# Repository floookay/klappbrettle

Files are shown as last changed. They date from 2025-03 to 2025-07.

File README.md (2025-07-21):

> [!CAUTION]
> This is still a work in progress and not yet fully tested! I messed up my last order from Mouser and need to get the missing components the next time I get to order.

# klappbrettle

a 40% ortho keyboard with a hinge

## design

I love using ortho keyboards but non-split ortho keyboards are getting uncomfortable for me fast so I thought about adding a hinge at the top.

It kind of resembles a starter clapper so that's where it got its name and athletics theme.

## pcb

PCBWay ([PCBWay.com](https://pcbway.com)) kindly offered to sponsor the pcb for this project that's why I got my hands on the pcbs within almost a week after ordering.  
The order process is straight forward and you also get an instant quote before ordering. After placing the order a technician checked and corrected the drill holes of the mouse bits within a few hours and the pcb was sent to manufacturing.
I'm impressed with the speed an quality of the pcb, see below:

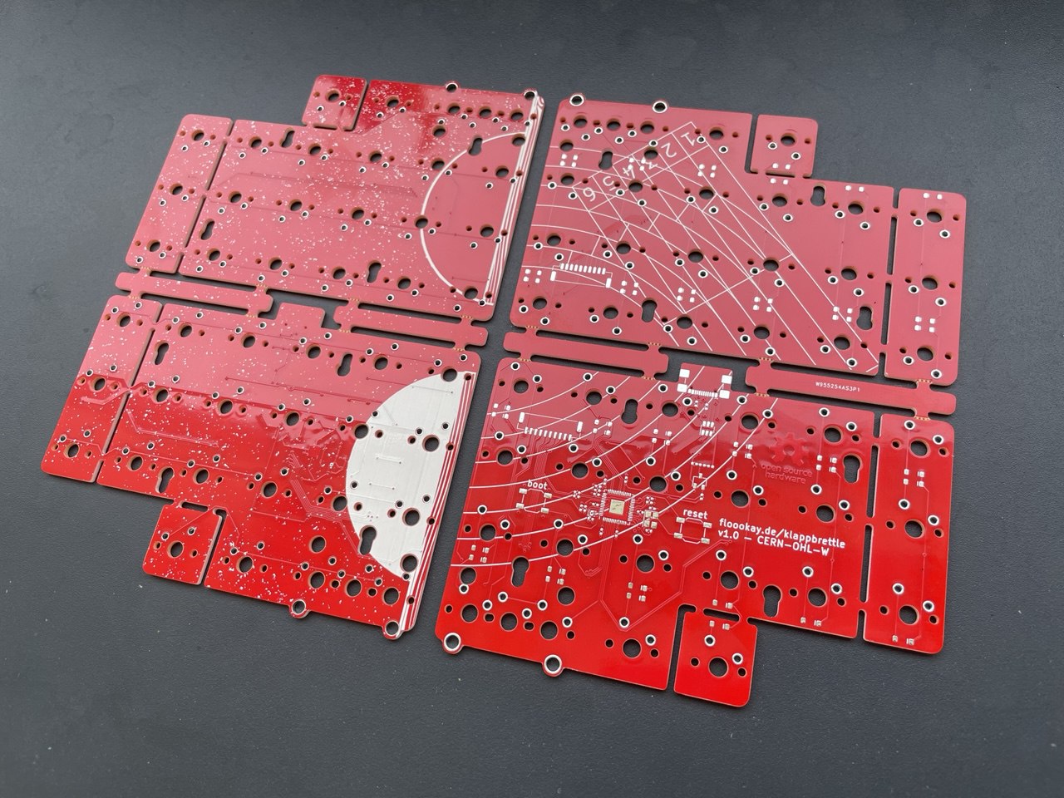
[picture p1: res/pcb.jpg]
pcb


The pcb is a two panel design where both sides are connected via a 10 pin JST connector. It's powered by a RP2040 microcontroller so there is plenty of flash storage. You can clip off the mod columns or the outer thumb key if want to. There are also extra holes where you can put grommets so the switches don't pop out of the 3mm plate.

- [x] complete the pcb design
- [ ] order missing components and solder

## case

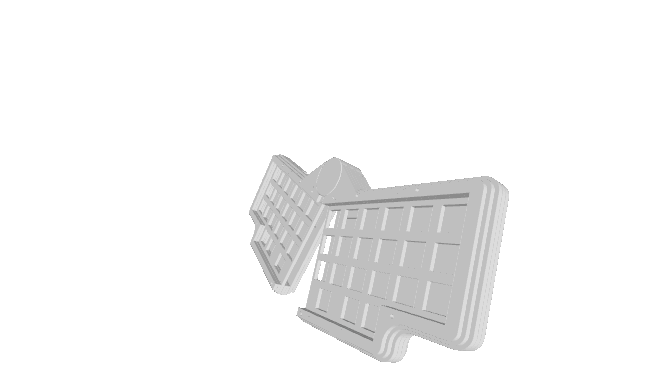
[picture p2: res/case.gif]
case gif, generated via imagetostl.com


The case is a 3mm acryl sandwich style case with a hinge to connect the halves and route the cable through. The hinge can be either 3d printed or can be 3mm acryl as well. I still need to test what works best, so far I only have a 3d printed prototype at hand.

- [x] complete the acrylic case design
- [ ] make the bottom plates look a bit nicer
- [ ] prepare dxf files and variants for laser cutting

## firmware

This will be powered by QMK but the firmware isn't ready yet.

- [ ] finish qmk firmware
- [ ] add vial support

## acknowledgements

Huge thanks to PCBWay for offering to sponsor this project, hlord2000 for their [RP2040 KiCAD template](https://github.com/hlord2000/Ohmbedded-RP2040-PCB-Template) as well as the ClackTales community for helping me with the theme.

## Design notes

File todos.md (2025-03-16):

- case usb cutout
- test print
- pcb mouse cuts
- pcb routing

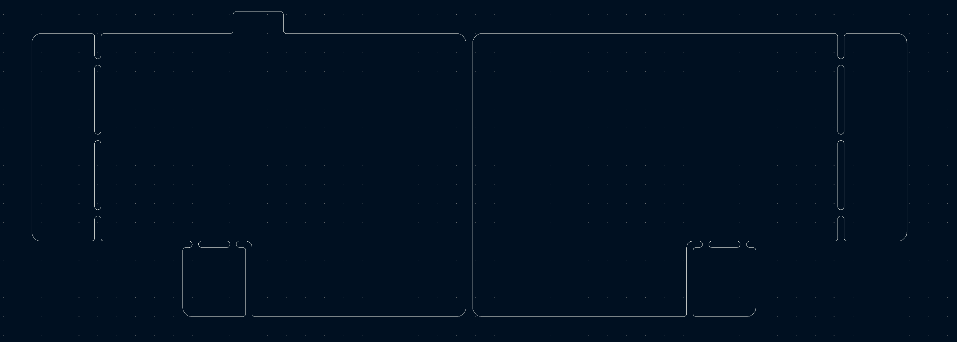
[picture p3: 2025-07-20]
pcb/outline.png

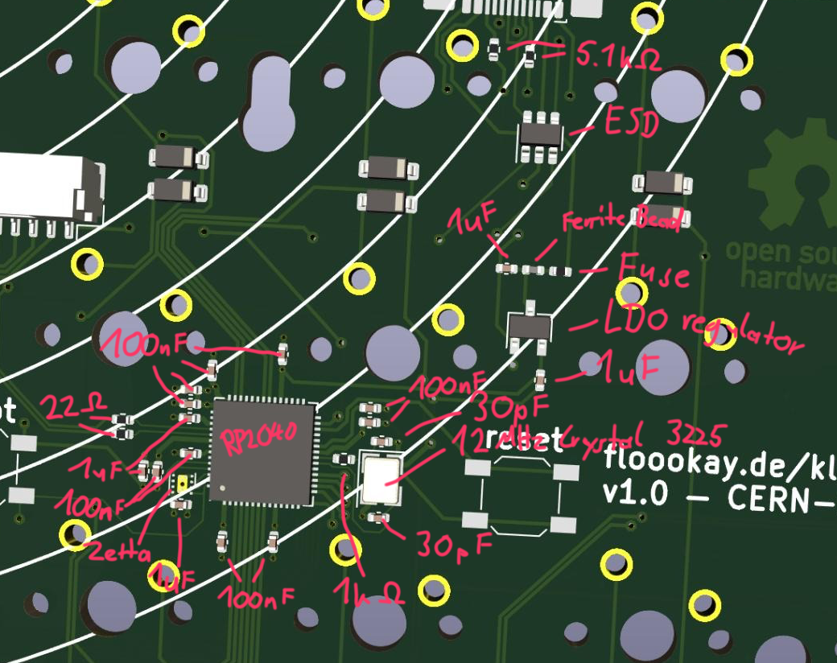
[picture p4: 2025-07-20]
pcb/placement.png

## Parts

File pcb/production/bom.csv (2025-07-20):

Designator | Footprint | Quantity | Value | LCSC Part #
C1, C2 | 0402 | 2 | 30p | C1562
C10, C12, C13, C15, C3 | 0402 | 5 | 1u | C52923
C11, C14, C16, C17, C4, C5, C6, C7, C8, C9 | 0402 | 10 | 100n | C1525
D1, D10, D11, D12, D13, D14, D15, D16, D17, D18, D19, D2, D20, D21, D22, D23, D24, D25, D26, D27, D28, D29, D3, D30, D31, D32, D33, D34, D35, D36, D37, D38, D39, D4, D40, D41, D42, D43, D44, D5, D6, D7, D8, D9 | D_SOD-123-minimal | 44 | D_45deg
F1 | 0402 | 1 | 700mA | C914086
FB1 | 0402 | 1 | 100 Ohm @ 100 MHz | C85812
J1 | USB_C_Receptacle_GCT_USB4110 | 1 | USB_C_Receptacle_USB2.0 | C9002
J2, J3 | JST_GH_SM10B-GHS-TB_1x10-1MP_P1.25mm_Horizontal | 2 | Conn_01x10 | C2683602
MX1, MX10, MX11, MX12, MX13, MX14, MX15, MX16, MX17, MX18, MX19, MX2, MX20, MX21, MX22, MX23, MX24, MX25, MX26, MX27, MX28, MX29, MX3, MX30, MX31, MX32, MX33, MX34, MX35, MX36, MX37, MX38, MX39, MX4, MX40, MX41, MX42, MX43, MX44, MX45, MX46, MX5, MX6, MX7, MX8, MX9 | SW_MX_1u | 46 | MX_SW_solder
R1, R2 | 0402 | 2 | 22 | C25152
R3 | 0402 | 1 | 1k | C106235
R4, R5 | 0402 | 2 | 5.1k | C25905
S1, S2 | STAB_MX_P_2u | 2 | MX_stab
SW72, SW73 | SW_SPST_SKQG_WithoutStem | 2 | SW_Push | C115351
U1 | QFN-56-1EP_7x7mm_P0.4mm_EP3.2x3.2mm_ThermalVias | 1 | RP2040 | C2040
U3 | SOT-23-6 | 1 | USBLC6-2SC6 | C558442
U4 | TSOT-23 | 1 | 3.3V Fixed Regulator | C150715
U5 | USON-8_1.5x1.5mm_P0.45mm | 1 | ZD25D40CNJGR | C3646778
Y1 | Crystal_SMD_3225-4Pin_3.2x2.5mm | 1 | 12MHz Crystal 3225 | C9002

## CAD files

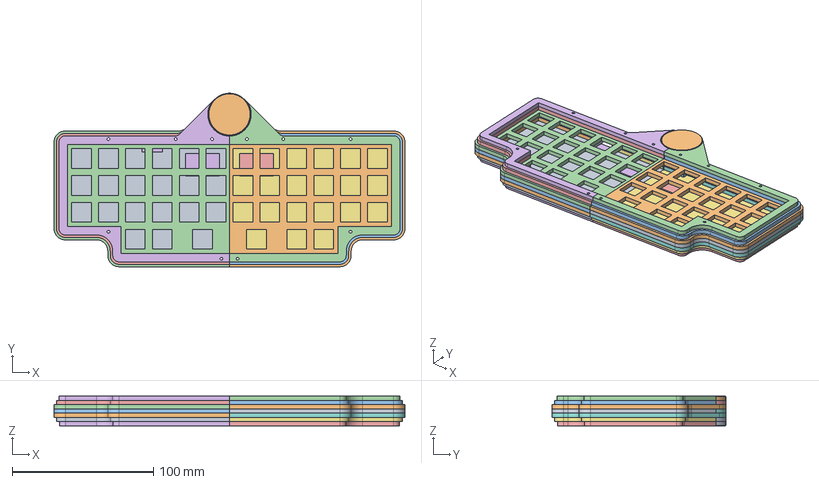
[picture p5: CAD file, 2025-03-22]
acrylic case/case.FCStd
248.6 x 122.9 x 21.0 mm
left_0_bottom
left_1_spacer
left_2_spacer
left_3_plate
left_4_rim
left_5_rim
right_0_bottom
right_1_spacer
right_2_spacer
right_3_plate
right_4_rim
right_5_rim
right_00_bottom
left_00_bottom
left_1_spacer2
left_2_spacer2
pin_bottom
pin_top

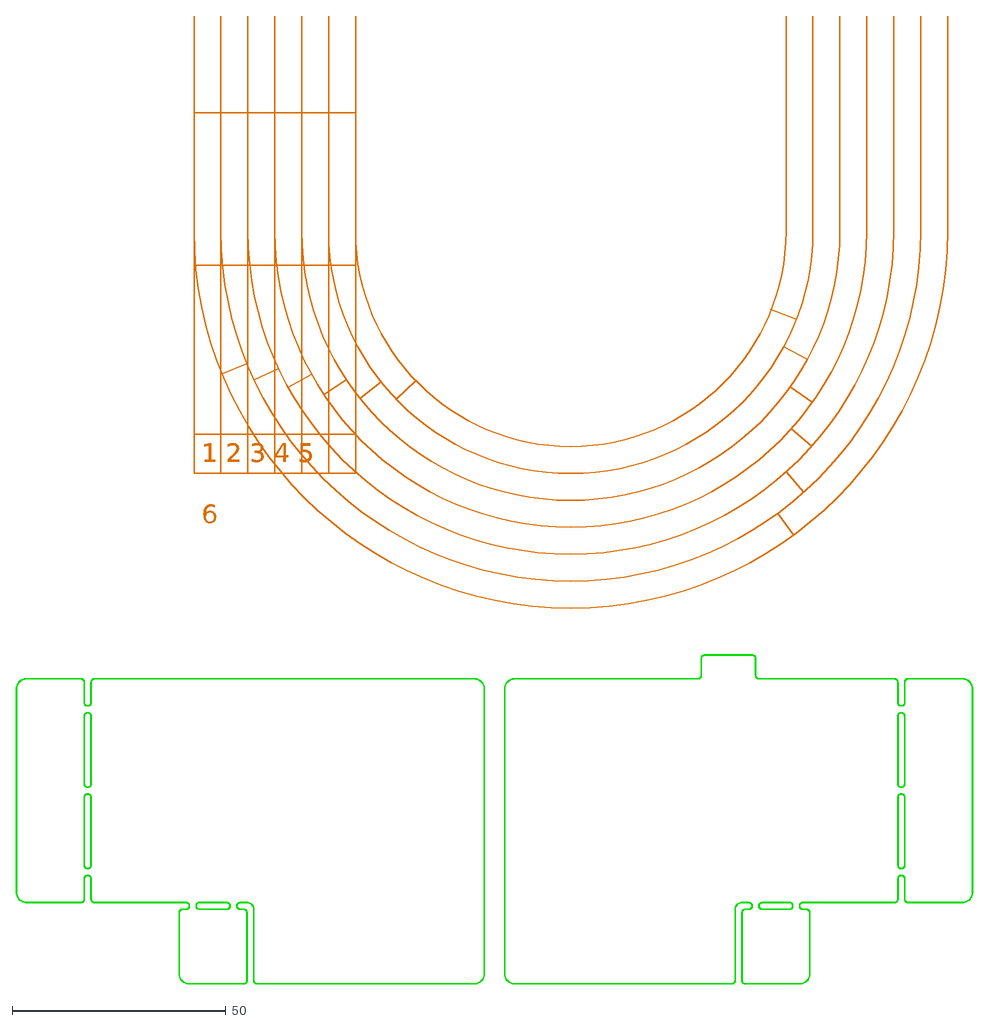
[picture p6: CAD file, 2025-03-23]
pcb/silk_bottom.dxf
1 2 3 4 5 6

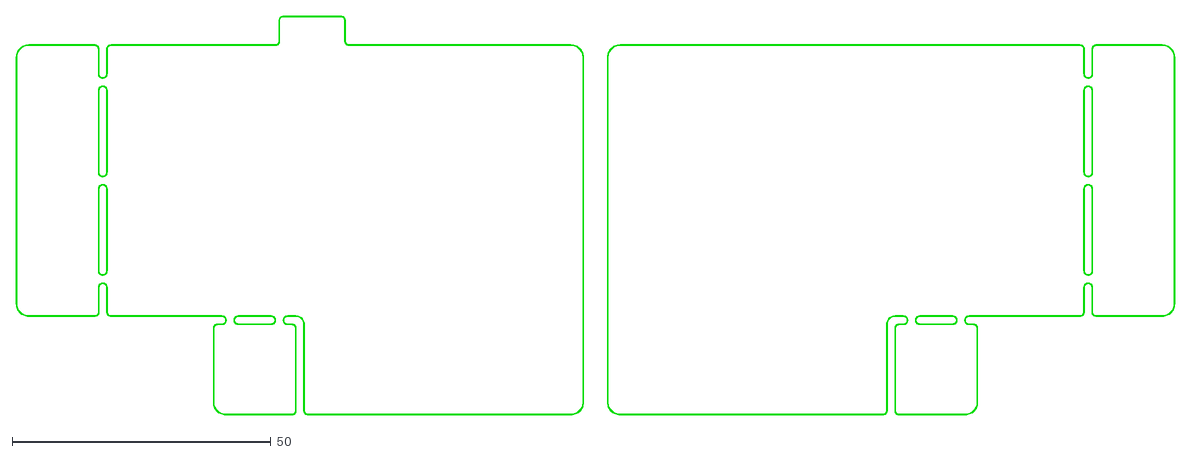
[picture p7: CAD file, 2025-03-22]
pcb/silk_top.dxf
223.9 x 77.0

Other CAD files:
acrylic case/case.3mf

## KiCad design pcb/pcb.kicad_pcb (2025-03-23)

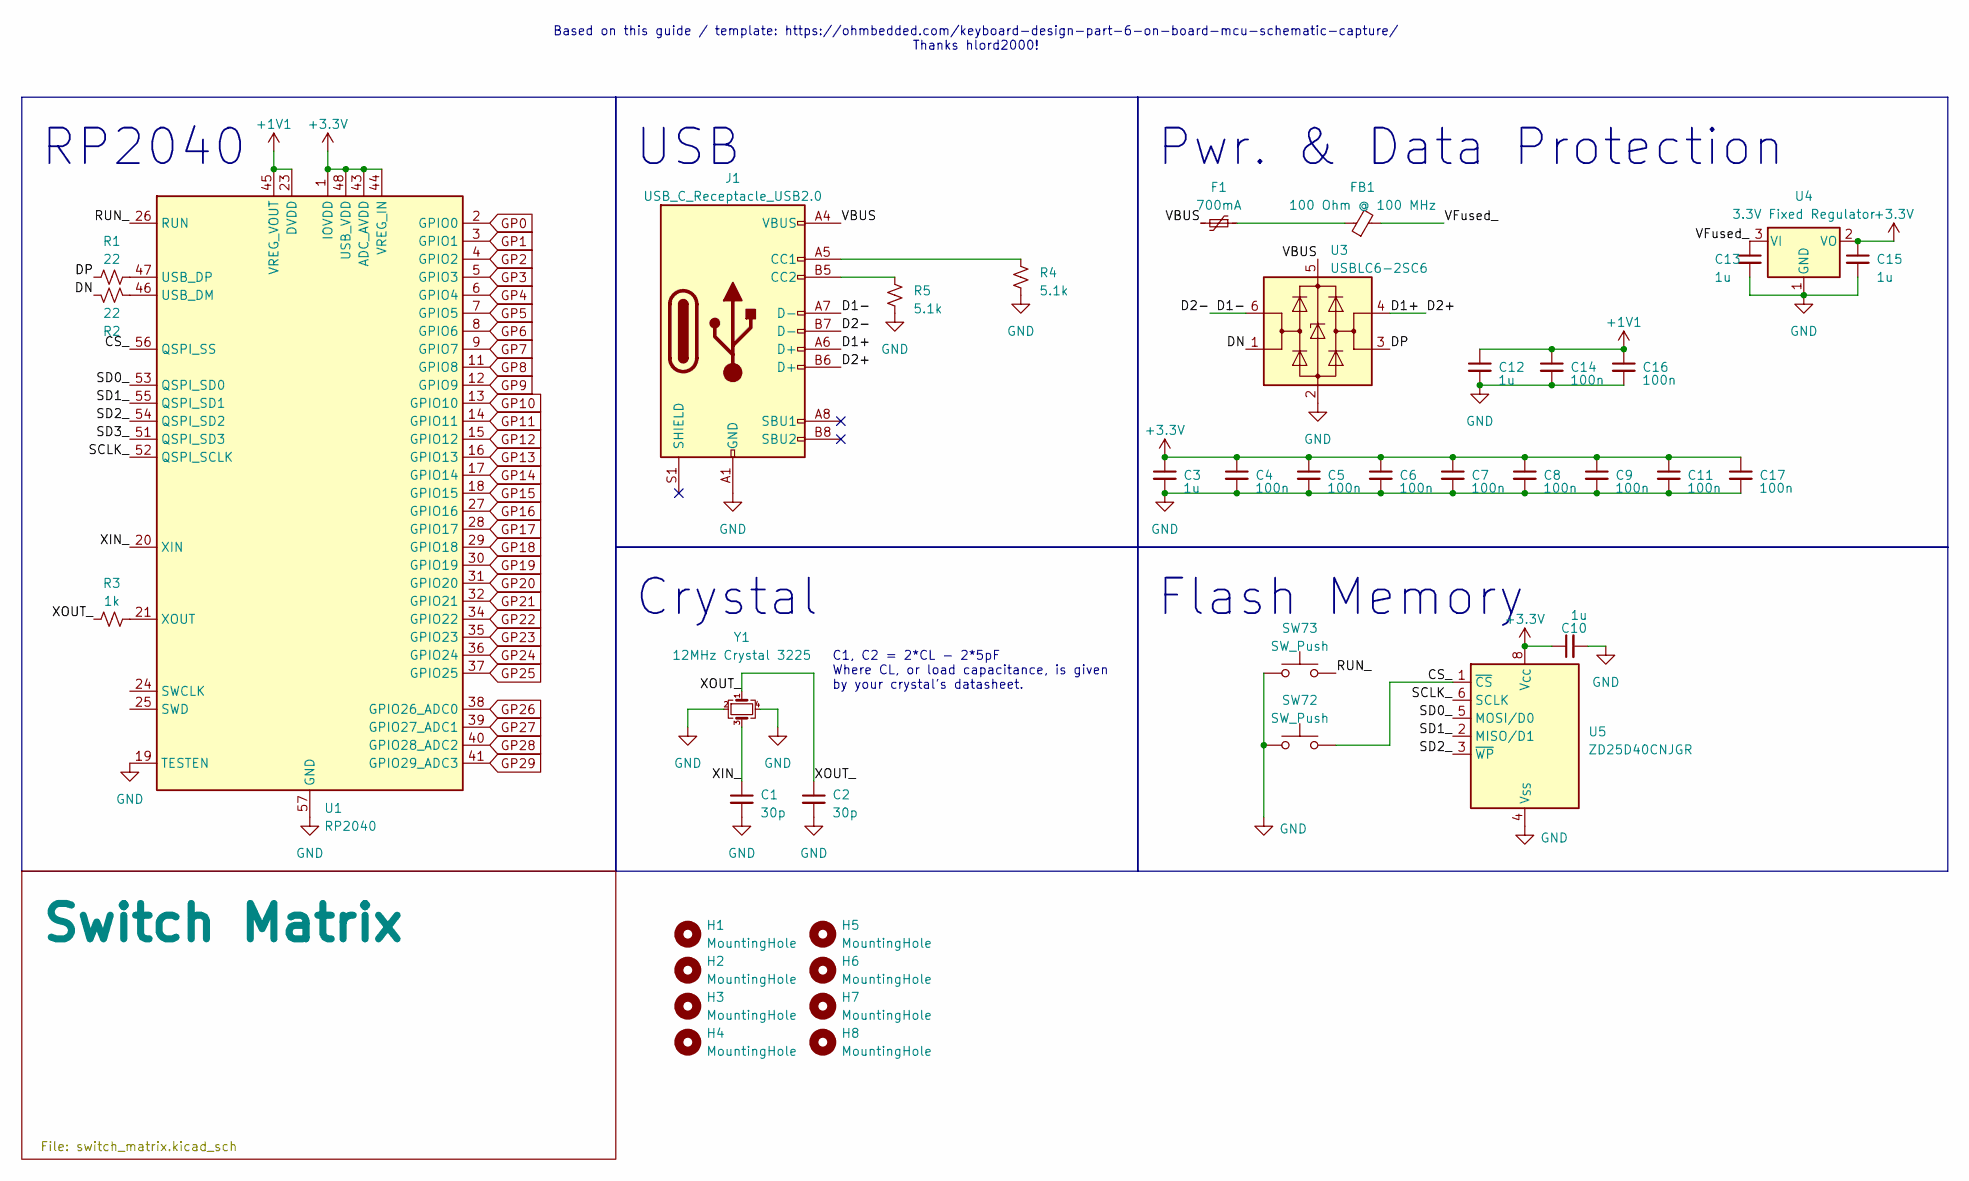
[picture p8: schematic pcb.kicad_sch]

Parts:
C1, C2: 30p; C_0402_1005Metric; LCSC C1562
C3, C10, C12, C13, C15: 1u; C_0402_1005Metric; LCSC C52923
C4, C5, C6, C7, C8, C9, C11, C14, C16, C17: 100n; C_0402_1005Metric; LCSC C1525
F1: 700mA; Fuse_0402_1005Metric; LCSC C914086
FB1: 100 Ohm @ 100 MHz; L_0402_1005Metric; LCSC C85812
H1, H2, H3, H4, H5, H6, H7, H8: MountingHole; spacer_hole_4mm
J1: USB_C_Receptacle_USB2.0; USB_C_Receptacle_GCT_USB4110
R1, R2: 22; R_0402_1005Metric; LCSC C25152
R3: 1k; R_0402_1005Metric; LCSC C106235
R4, R5: 5.1k; R_0402_1005Metric; LCSC C25905
SW72, SW73: SW_Push; SW_SPST_SKQG_WithoutStem; LCSC C115351
U1: RP2040; QFN-56-1EP_7x7mm_P0.4mm_EP3.2x3.2mm_ThermalVias; LCSC C2040
U3: USBLC6-2SC6; SOT-23-6; LCSC C558442
U4: 3.3V Fixed Regulator; TSOT-23; LCSC C150715
U5: ZD25D40CNJGR; USON-8_1.5x1.5mm_P0.45mm; LCSC C3646778
Y1: 12MHz Crystal 3225; Crystal_SMD_3225-4Pin_3.2x2.5mm; LCSC C9002

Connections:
+1V1: C12.1, C14.1, C16.1, U1.23 (DVDD), U1.45 (VREG_VOUT), U1.50 (DVDD)
+3.3V: C3.1, C4.1, C5.1, C6.1, C7.1, C8.1, C9.1, C10.1, C11.1, C15.1, C17.1, U1.1 (IOVDD), U1.10 (IOVDD), U1.22 (IOVDD), U1.33 (IOVDD), U1.42 (IOVDD), U1.43 (ADC_AVDD), U1.44 (VREG_IN), U1.48 (USB_VDD), U1.49 (IOVDD), U4.2 (VO), U5.8 (V_{CC})
/CS_: SW72.2, U1.56 (QSPI_SS), U5.1 (~CS)
/D1+: J1.A6 (D+), J1.B6 (D+), U3.4 (I/O2)
/D1-: J1.A7 (D-), J1.B7 (D-), U3.6 (I/O1)
/DN: R2.2, U3.1 (I/O1)
/DP: R1.1, U3.3 (I/O2)
/RUN_: SW73.2, U1.26 (RUN)
/SCLK_: U1.52 (QSPI_SCLK), U5.6 (SCLK)
/SD0_: U1.53 (QSPI_SD0), U5.5 (MOSI/D0)
/SD1_: U1.55 (QSPI_SD1), U5.2 (MISO/D1)
/SD2_: U1.54 (QSPI_SD2), U5.3 (~WP)
/SD3_: U1.51 (QSPI_SD3)
/VBUS: F1.2, J1.A4 (VBUS), J1.A9 (VBUS), J1.B4 (VBUS), J1.B9 (VBUS), U3.5 (VBUS)
/VFused_: C13.1, FB1.2, U4.3 (VI)
/XIN_: C1.1, U1.20 (XIN), Y1.3
/XOUT_: C2.1, R3.1, Y1.1
GND: C1.2, C2.2, C3.2, C4.2, C5.2, C6.2, C7.2, C8.2, C9.2, C10.2, C11.2, C12.2, C13.2, C14.2, C15.2, C16.2, C17.2, J1.A1 (GND), J1.A12 (GND), J1.B1 (GND), J1.B12 (GND), R4.1, R5.1, SW72.1, SW73.1, U1.19 (TESTEN), U1.57 (GND), U3.2 (GND), U4.1 (GND), U5.4 (V_{SS}), U5.9 (PAD/V_{SS}), Y1.2, Y1.4
GP0: U1.2 (GPIO0)
GP1: U1.3 (GPIO1); also elsewhere on the board
GP2: U1.4 (GPIO2); also elsewhere on the board
GP3: U1.5 (GPIO3); also elsewhere on the board
GP4: U1.6 (GPIO4); also elsewhere on the board
GP5: U1.7 (GPIO5); also elsewhere on the board
GP6: U1.8 (GPIO6); also elsewhere on the board
GP7: U1.9 (GPIO7)
GP8: U1.11 (GPIO8)
GP9: U1.12 (GPIO9)
GP10: U1.13 (GPIO10)
GP11: U1.14 (GPIO11); also elsewhere on the board
GP12: U1.15 (GPIO12); also elsewhere on the board
GP13: U1.16 (GPIO13); also elsewhere on the board
GP14: U1.17 (GPIO14); also elsewhere on the board
GP15: U1.18 (GPIO15); also elsewhere on the board
GP16: U1.27 (GPIO16); also elsewhere on the board
GP17: U1.28 (GPIO17)
GP18: U1.29 (GPIO18)
GP19: U1.30 (GPIO19)
GP20: U1.31 (GPIO20)
GP21: U1.32 (GPIO21)
GP22: U1.34 (GPIO22)
GP23: U1.35 (GPIO23); also elsewhere on the board
GP24: U1.36 (GPIO24); also elsewhere on the board
GP25: U1.37 (GPIO25)
GP26: U1.38 (GPIO26_ADC0)
GP27: U1.39 (GPIO27_ADC1)
GP28: U1.40 (GPIO28_ADC2); also elsewhere on the board
GP29: U1.41 (GPIO29_ADC3); also elsewhere on the board
unnamed: F1.1, FB1.1
unnamed: J1.A5 (CC1), R4.2
unnamed: J1.B5 (CC2), R5.2
unnamed: R2.1, U1.46 (USB_DM)
unnamed: R1.2, U1.47 (USB_DP)
unnamed: R3.2, U1.21 (XOUT)

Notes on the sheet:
Flash Memory
Pwr. & Data Protection
Based on this guide / template: https://ohmbedded.com/keyboard-design-part-6-on-board-mcu-schematic-capture/ Thanks hlord2000!
C1, C2 = 2*CL - 2*5pF Where CL, or load capacitance, is given by your crystal's datasheet.
Crystal
RP2040
USB

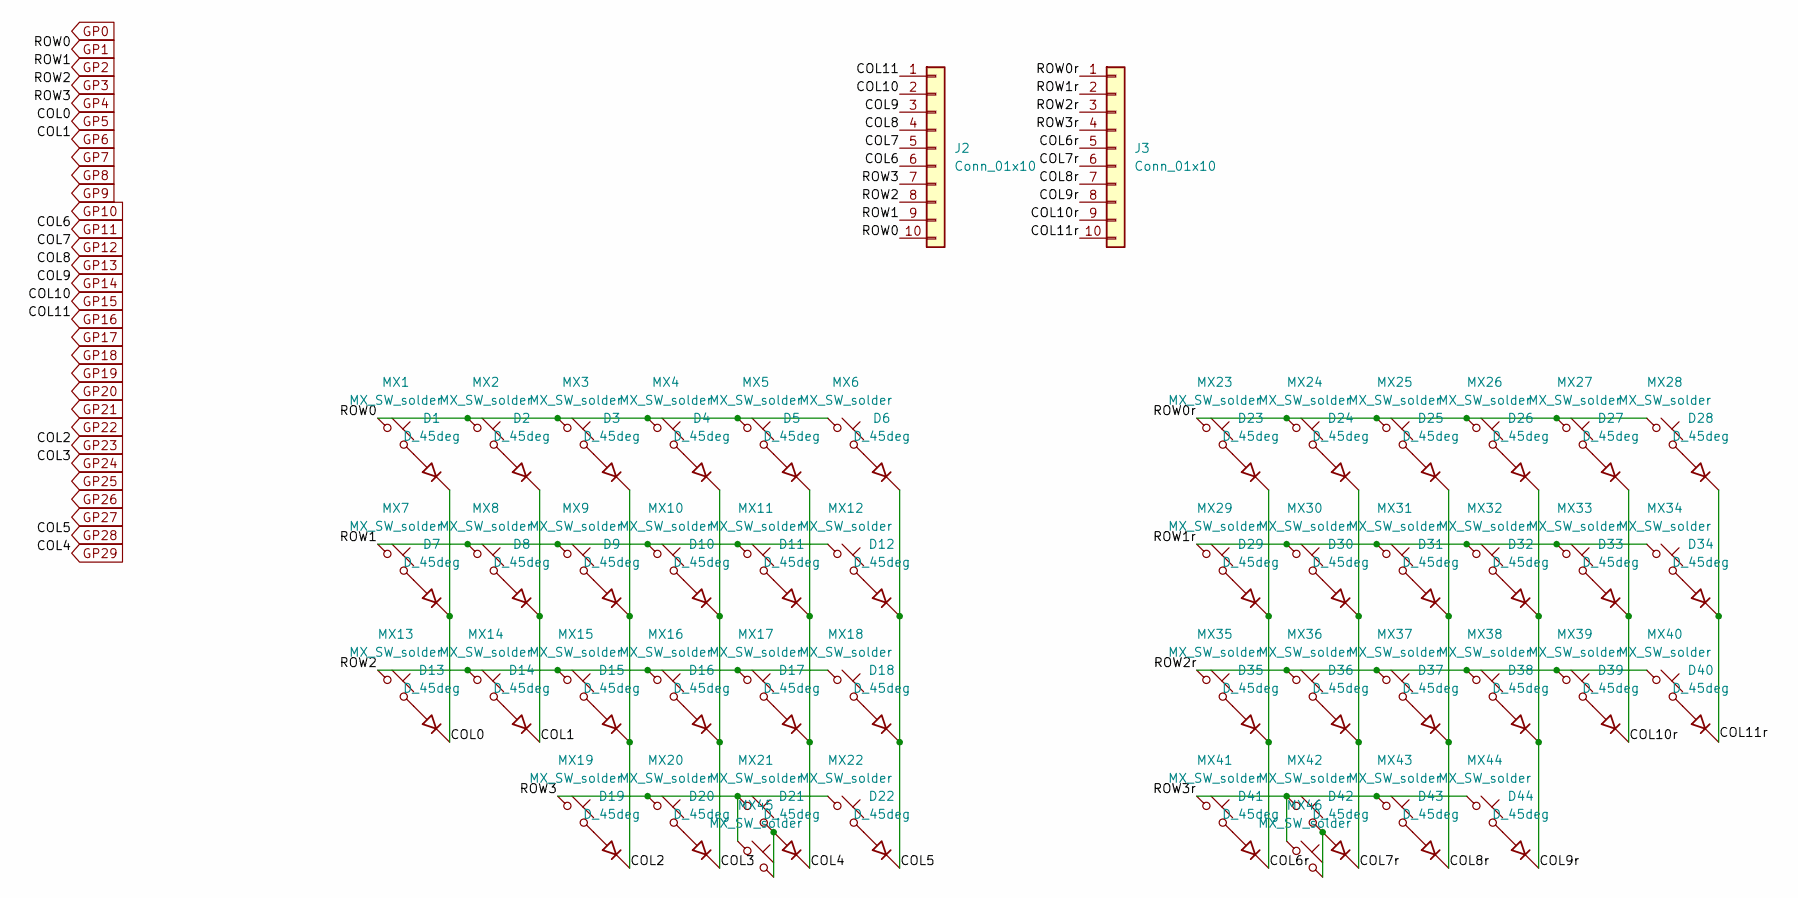
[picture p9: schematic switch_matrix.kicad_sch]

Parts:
D1, D2, D3, D4, D5, D6, D7, D8, D9, D10, D11, D12, D13, D14, D15, D16, D17, D18, D19, D20, D21, D22, D23, D24, D25, D26, D27, D28, D29, D30, D31, D32, D33, D34, D35, D36, D37, D38, D39, D40, D41, D42, D43, D44: D_45deg; D_SOD-123-minimal
J2, J3: Conn_01x10; JST_GH_SM10B-GHS-TB_1x10-1MP_P1.25mm_Horizontal
MX1, MX2, MX3, MX4, MX5, MX6, MX7, MX8, MX9, MX10, MX11, MX12, MX13, MX14, MX15, MX16, MX17, MX18, MX19, MX20, MX21, MX22, MX23, MX24, MX25, MX26, MX27, MX28, MX29, MX30, MX31, MX32, MX33, MX34, MX35, MX36, MX37, MX38, MX39, MX40, MX41, MX42, MX43, MX44, MX45, MX46: MX_SW_solder; SW_MX_1u

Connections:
/Switch Matrix/COL6r: D23.1 (K), D29.1 (K), D35.1 (K), D41.1 (K), J3.5
/Switch Matrix/COL7r: D24.1 (K), D30.1 (K), D36.1 (K), D42.1 (K), J3.6
/Switch Matrix/COL8r: D25.1 (K), D31.1 (K), D37.1 (K), D43.1 (K), J3.7
/Switch Matrix/COL9r: D26.1 (K), D32.1 (K), D38.1 (K), D44.1 (K), J3.8
/Switch Matrix/COL10r: D27.1 (K), D33.1 (K), D39.1 (K), J3.9
/Switch Matrix/COL11r: D28.1 (K), D34.1 (K), D40.1 (K), J3.10
/Switch Matrix/ROW0r: J3.1, MX23.1, MX24.1, MX25.1, MX26.1, MX27.1, MX28.1
/Switch Matrix/ROW1r: J3.2, MX29.1, MX30.1, MX31.1, MX32.1, MX33.1, MX34.1
/Switch Matrix/ROW2r: J3.3, MX35.1, MX36.1, MX37.1, MX38.1, MX39.1, MX40.1
/Switch Matrix/ROW3r: J3.4, MX41.1, MX42.1, MX43.1, MX44.1, MX46.1
GP1: J2.10, MX1.1, MX2.1, MX3.1, MX4.1, MX5.1, MX6.1; also elsewhere on the board
GP2: J2.9, MX7.1, MX8.1, MX9.1, MX10.1, MX11.1, MX12.1; also elsewhere on the board
GP3: J2.8, MX13.1, MX14.1, MX15.1, MX16.1, MX17.1, MX18.1; also elsewhere on the board
GP4: J2.7, MX19.1, MX20.1, MX21.1, MX22.1, MX45.1; also elsewhere on the board
GP5: D1.1 (K), D7.1 (K), D13.1 (K); also elsewhere on the board
GP6: D2.1 (K), D8.1 (K), D14.1 (K); also elsewhere on the board
GP11: J2.6; also elsewhere on the board
GP12: J2.5; also elsewhere on the board
GP13: J2.4; also elsewhere on the board
GP14: J2.3; also elsewhere on the board
GP15: J2.2; also elsewhere on the board
GP16: J2.1; also elsewhere on the board
GP23: D3.1 (K), D9.1 (K), D15.1 (K), D19.1 (K); also elsewhere on the board
GP24: D4.1 (K), D10.1 (K), D16.1 (K), D20.1 (K); also elsewhere on the board
GP28: D6.1 (K), D12.1 (K), D18.1 (K), D22.1 (K); also elsewhere on the board
GP29: D5.1 (K), D11.1 (K), D17.1 (K), D21.1 (K); also elsewhere on the board
unnamed: D1.2 (A), MX1.2
unnamed: D2.2 (A), MX2.2
unnamed: D3.2 (A), MX3.2
unnamed: D4.2 (A), MX4.2
unnamed: D5.2 (A), MX5.2
unnamed: D6.2 (A), MX6.2
unnamed: D7.2 (A), MX7.2
unnamed: D8.2 (A), MX8.2
unnamed: D9.2 (A), MX9.2
unnamed: D10.2 (A), MX10.2
unnamed: D11.2 (A), MX11.2
unnamed: D12.2 (A), MX12.2
unnamed: D13.2 (A), MX13.2
unnamed: D14.2 (A), MX14.2
unnamed: D15.2 (A), MX15.2
unnamed: D16.2 (A), MX16.2
unnamed: D17.2 (A), MX17.2
unnamed: D18.2 (A), MX18.2
unnamed: D19.2 (A), MX19.2
unnamed: D20.2 (A), MX20.2
unnamed: D21.2 (A), MX21.2, MX45.2
unnamed: D22.2 (A), MX22.2
unnamed: D23.2 (A), MX23.2
unnamed: D24.2 (A), MX24.2
unnamed: D25.2 (A), MX25.2
unnamed: D26.2 (A), MX26.2
unnamed: D27.2 (A), MX27.2
unnamed: D28.2 (A), MX28.2
unnamed: D29.2 (A), MX29.2
unnamed: D30.2 (A), MX30.2
unnamed: D31.2 (A), MX31.2
unnamed: D32.2 (A), MX32.2
unnamed: D33.2 (A), MX33.2
unnamed: D34.2 (A), MX34.2
unnamed: D35.2 (A), MX35.2
unnamed: D36.2 (A), MX36.2
unnamed: D37.2 (A), MX37.2
unnamed: D38.2 (A), MX38.2
unnamed: D39.2 (A), MX39.2
unnamed: D40.2 (A), MX40.2
unnamed: D41.2 (A), MX41.2
unnamed: D42.2 (A), MX42.2, MX46.2
unnamed: D43.2 (A), MX43.2
unnamed: D44.2 (A), MX44.2

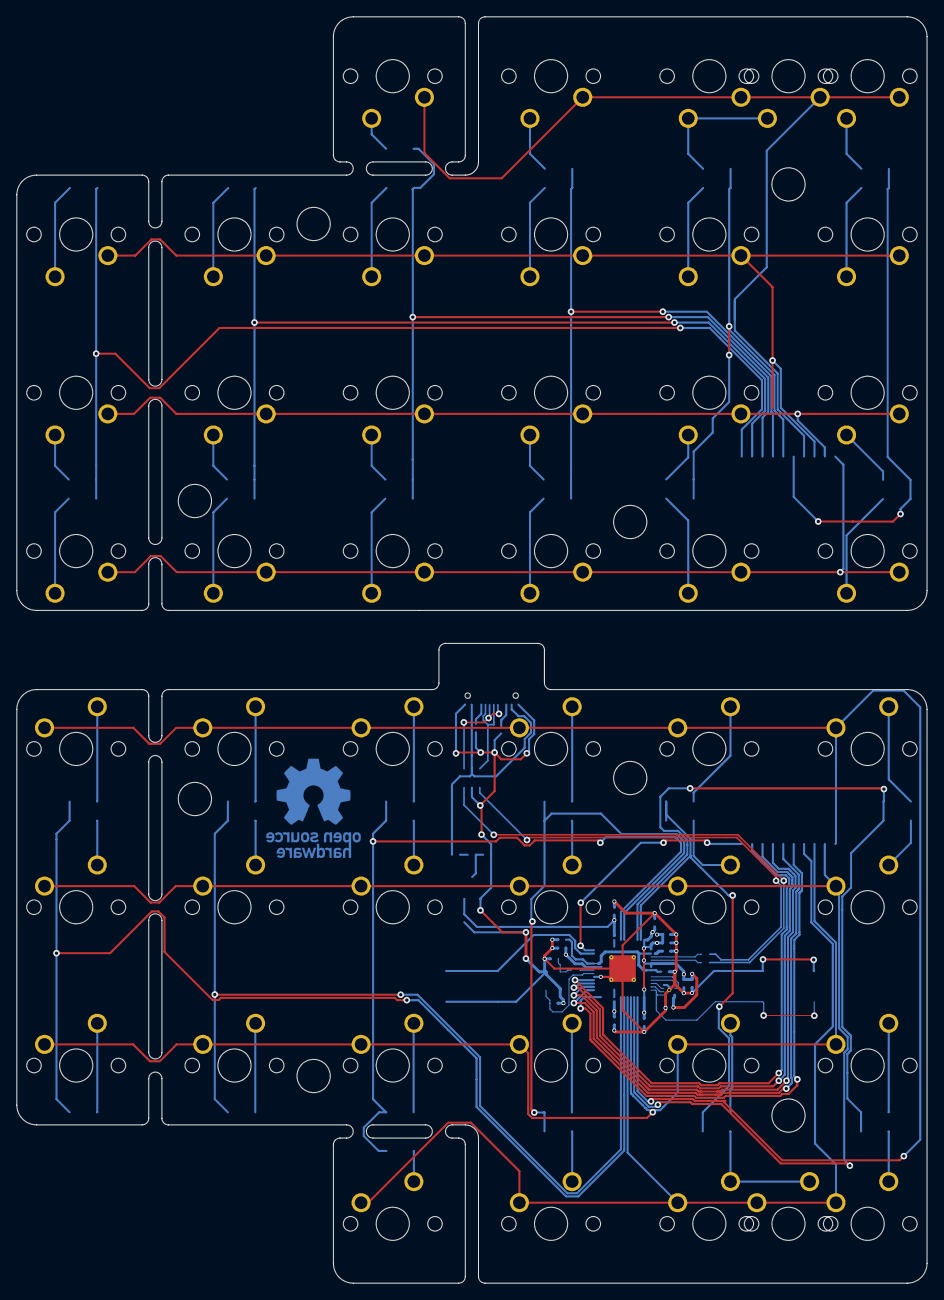
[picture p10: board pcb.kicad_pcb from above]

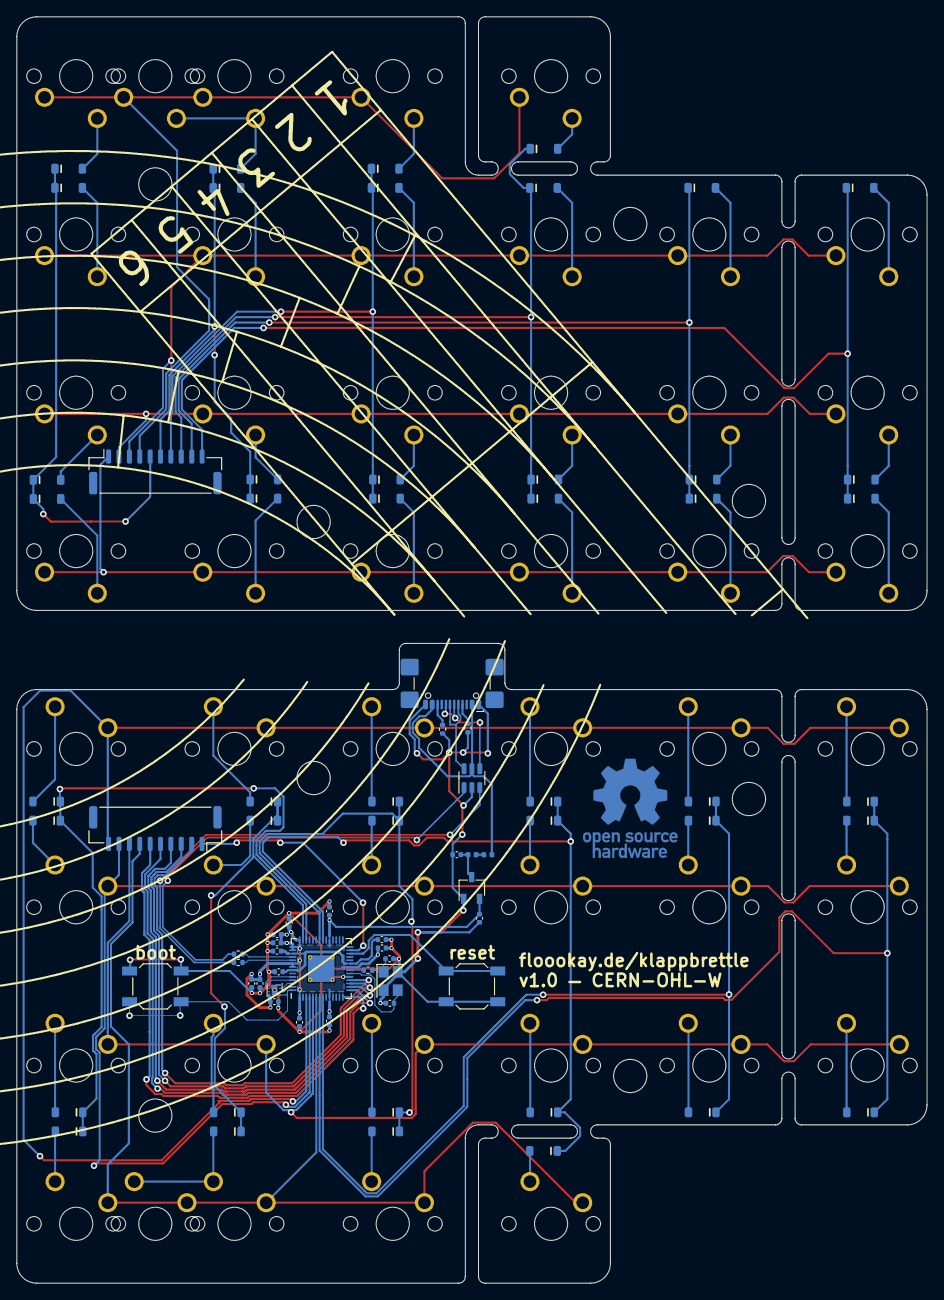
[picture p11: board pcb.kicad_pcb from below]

Board: 4 copper layers, 109.5 x 152.4 mm, 132 parts (78 on the bottom side), 93 nets.

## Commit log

2025-02-15 added prototype of left half
    [case.FCStd]
2025-02-24 added right half
    [case.FCStd]
2025-02-25 added pcb
    [pcb.kicad_pcb, pcb.kicad_sch]
2025-03-07 added basic layout
    [pcb.kicad_pcb, pcb.kicad_sch]
2025-03-14 fixed connections
    [pcb.kicad_pcb, pcb.kicad_sch]
2025-03-16 imported template for rp2040 components
    [pcb.kicad_pcb, pcb.kicad_sch, switch_matrix.kicad_sch]
2025-03-16 updated case design with stepped layers
    [case.FCStd]
2025-03-16 added jst cutouts
    [case.FCStd]
2025-03-16 enlarged standoffs
    [case.FCStd]
2025-03-21 added usb cutout and hinge pin
    [case.FCStd]
2025-03-21 added some more routing
    [pcb.kicad_pcb, pcb.kicad_sch, switch_matrix.kicad_sch]
2025-03-21 added case stl files
    [case.3mf]
2025-03-22 added bottom silk draft
    [case.3mf, case.FCStd, silk_bottom.dxf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]
2025-03-23 redid routing
    [pcb.kicad_pcb, pcb.kicad_sch, silk_bottom.dxf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]
2025-04-12 added silk, panels and stabs
    [switch_matrix.kicad_sch]
2025-04-12 turned 2 spacers around because of the stabs
2025-07-20 added latest files
    [bom.csv, case.3mf, case.FCStd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]
2026-10-09 added sliced case file
2026-10-09 updated kicad version
2026-10-11 made pin longer because my screws are too short

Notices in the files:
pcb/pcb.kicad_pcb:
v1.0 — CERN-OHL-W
